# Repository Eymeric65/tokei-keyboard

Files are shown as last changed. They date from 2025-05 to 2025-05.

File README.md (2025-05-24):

# tokei-keyboard
Official repository of the Tokei split keyboard.

This repository is split in the different component in order to make a working Tokei Split keyboard.

*If you are searching the kicad library used in this keyboard you should go to [this repository]*

## Kicad / PCB 

If you directly want to order your board you should directly check [JLCPCB production archive](/kicad/OUTPUT/final-JLCPCB.zip)

Otherwise Kicad project is divided in three :
- The left half
- The right half
- The paneliser to reunion both for production

Electrical output is stored into the **`JLCPCB`** directory, CAD related output is stored in **`CAD`** folder (don't hesitate to check)

## firmware

The `firmware` folder contain ready to flash files in order to test right away the keyboard.

## ZMK

The `zmk-config` file is a direct copy of my `zmk-config` fork for this keyboard. It is the base to the build of the keyboard.

## CAD 

The `CAD` folder contain everything related with the 3D printed cover. I work with Alibre but you can find the ready-to-use `.step` in the `CAD/export` folder.

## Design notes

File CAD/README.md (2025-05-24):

The folder containing everything related with CAD. 

If you are only interested in `.step` there are in export folder.

If you are not familiar with CAD I will strongly advise you to look out for [Alibre](https://www.alibre.com/fr/). From my research there are the only that propose afordable CAD software with forever licence that can be bought by hobbyist. 

Personnaly I came from CATIA (during studying) and even after making a CAR in CATIA (Formula Student), I don't see limitation in Alibre, even if it is a bit slower.

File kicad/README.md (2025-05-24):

Here you can find both of the Kicad project for the right and left halves of the keyboard.
There is also the result of the paneliser in order to merge both halves (cheaper).

I would advise to check the board with your supplier.

If you trust me entirely you can directly use the archive [JLCPC accepted gerber](/OUTPUT/final-JLCPCB.zip) (for reference $32.37 for 5 boards)

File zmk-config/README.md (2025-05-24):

This is a copy of my own version of the zmk-config repo for the Tokei keyboard. 
Not even all the key are binded so, I would advise to check the [keymap](/boards/shields/t_split/t_split.keymap) file.

Base Firmware can be found in the repository [firmware](../firmware/V1.0).

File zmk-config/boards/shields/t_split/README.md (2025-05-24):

#### Note to user:

Fork of the HELIX SHIELD

- If desired, RGB underglow must be manually enabled before building and flashing. Check 'helix.conf' to do so.
- Peripheral RGB function is impaired until full support is implemented in the master branch.
- OLED displays are not currently included in this shield. This will be updated after OLED support is live.
- 'KANA' and 'EISUU' input is currently utilized under the 'LANG1' and 'LANG2' keycodes respectively.

---

Thanks to Nicell, KemoNine, petejohanson, TJ "Chormbo The Great", joelspadin/Rinh, Wofiel, Okke, innovaker,
and the rest of the ZMK contributors for their support in constructing this shield. I appreciate your assistance greatly.
This has been a valuable learning experience for me. May this contribution serve the community well.

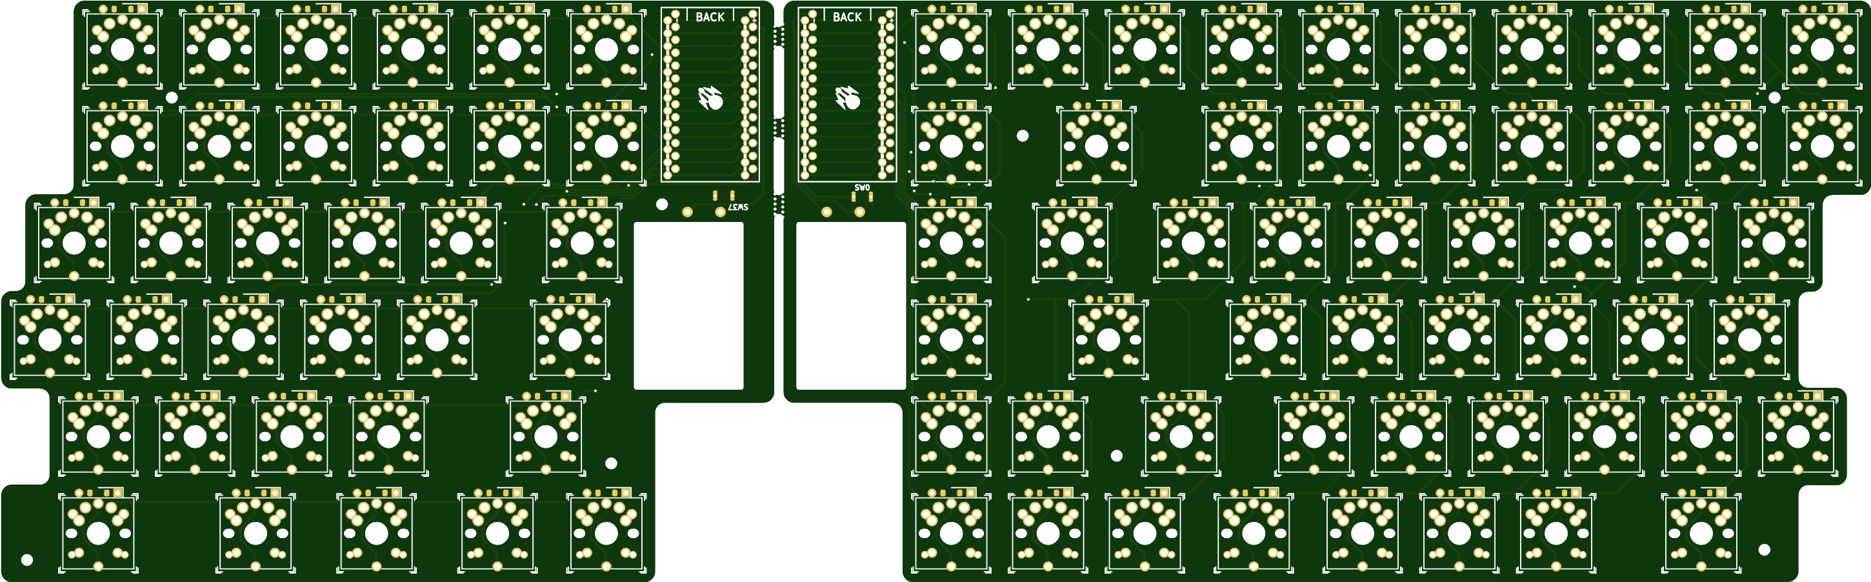
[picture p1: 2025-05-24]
kicad/paneliser/export/Final_Combined_Bottom.png

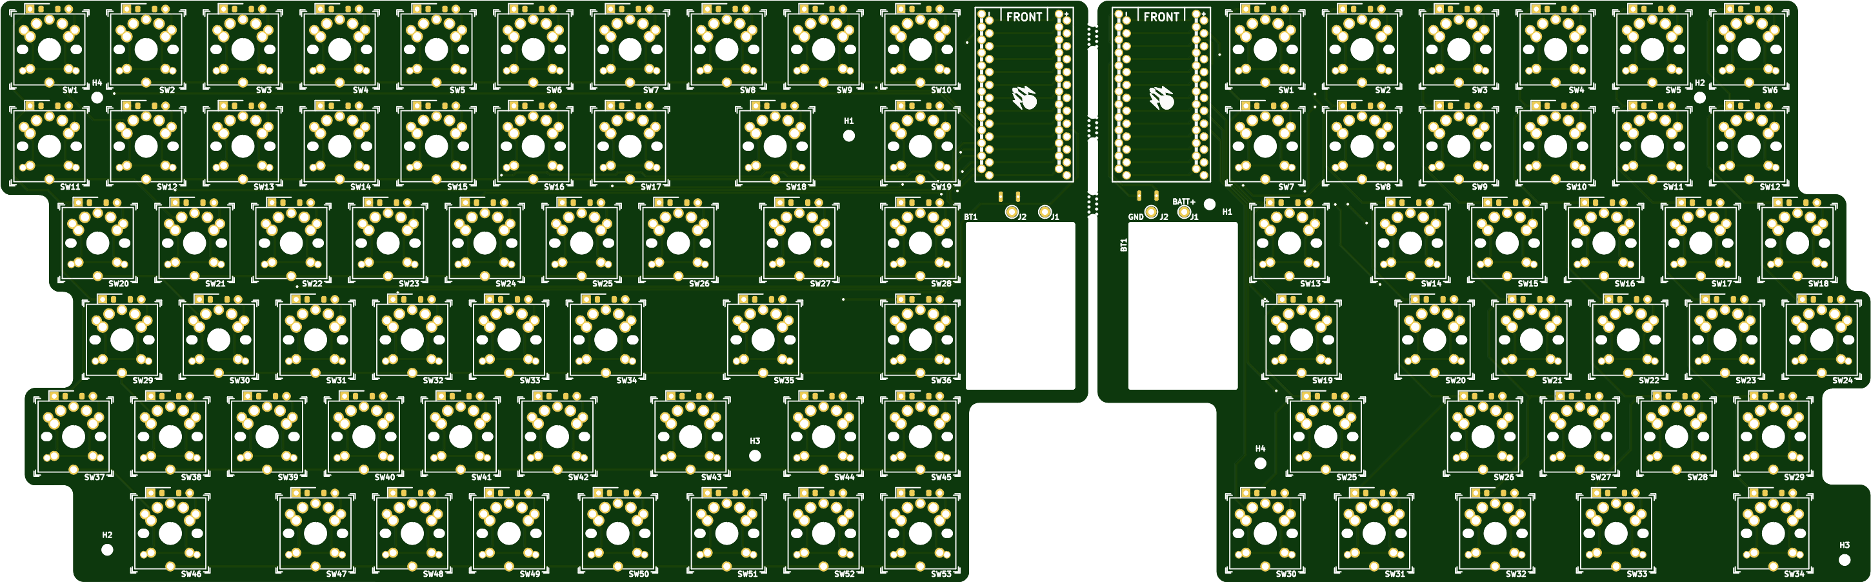
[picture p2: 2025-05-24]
kicad/paneliser/export/Final_Combined_Top.png

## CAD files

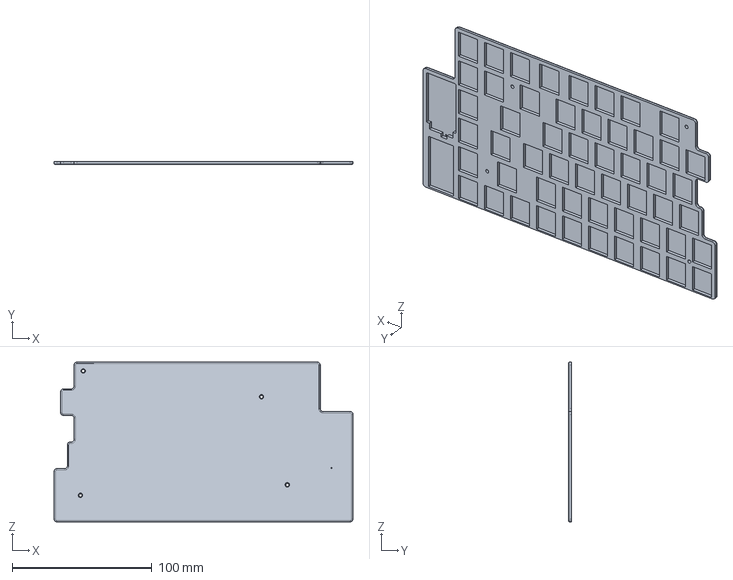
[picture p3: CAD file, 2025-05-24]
CAD/export/Bottom_cover_right_low_profile.stp
213.9 x 2.40 x 114.3 mm

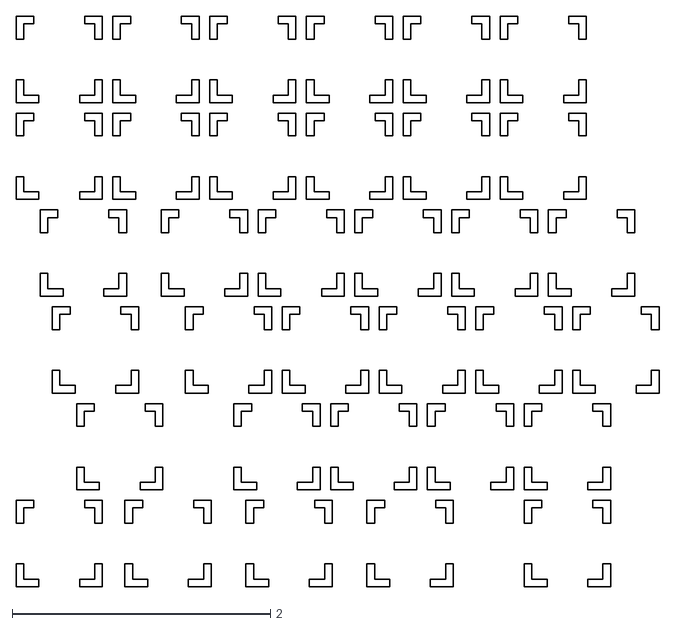
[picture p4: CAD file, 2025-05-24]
kicad/65_split_left/CAD/65_split_left-User_1.dxf
4.98 x 4.42

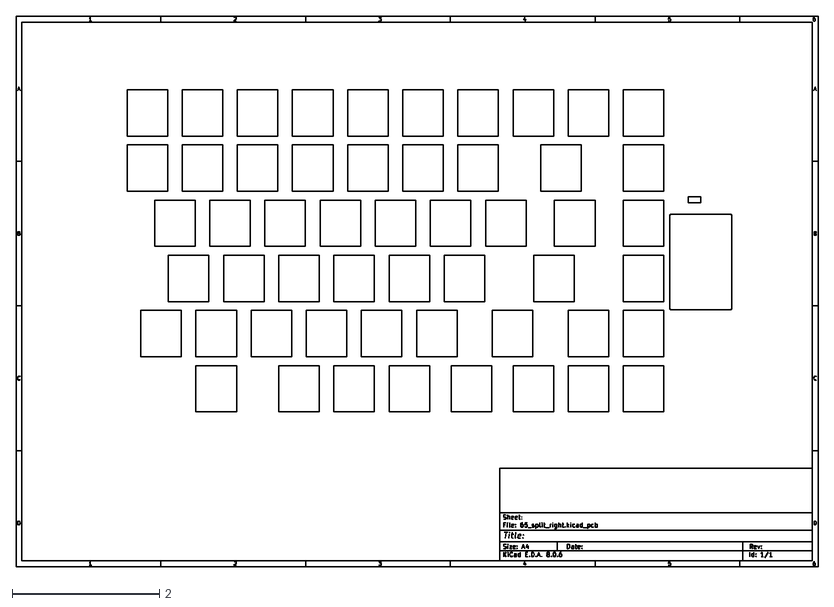
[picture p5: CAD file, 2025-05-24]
kicad/65_split_right/CAD/65_split_right-User_2.dxf
10.9 x 7.48

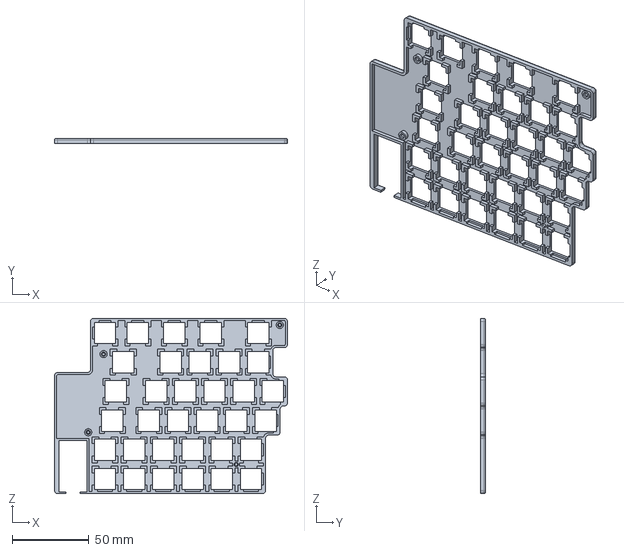
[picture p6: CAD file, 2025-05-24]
CAD/export/Top_cover_left_low_profile.stp
152.0 x 3.55 x 114.3 mm

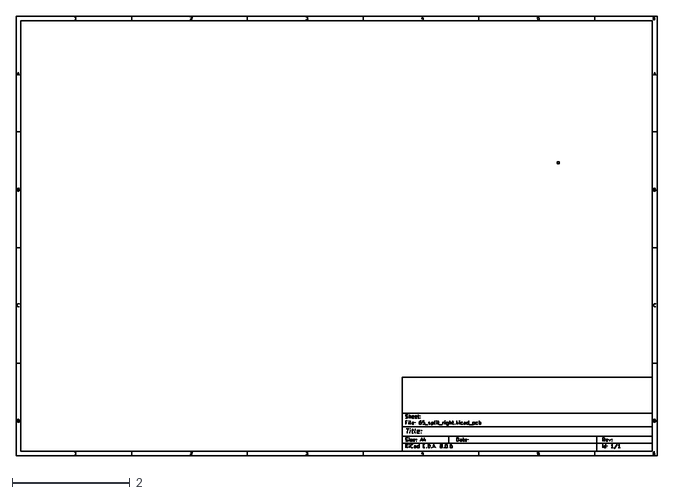
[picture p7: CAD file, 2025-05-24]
kicad/65_split_right/CAD/65_split_right-User_4.dxf
10.9 x 7.48

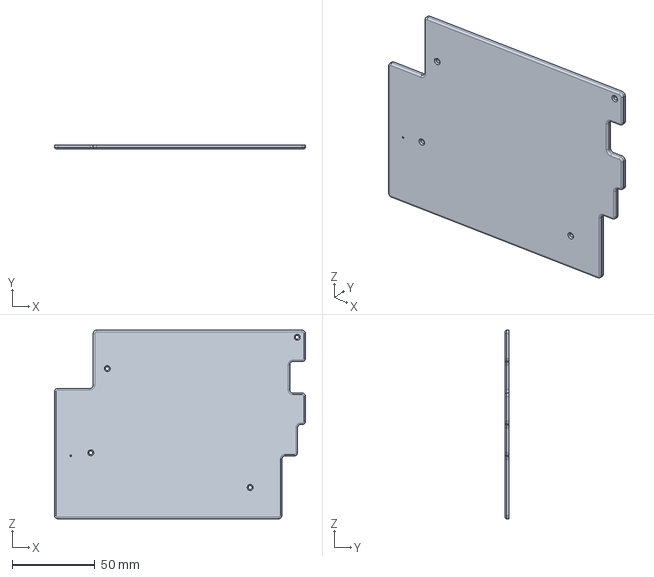
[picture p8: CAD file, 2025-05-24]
CAD/export/Bttom_cover_left_low_profile.stp
152.0 x 2.40 x 114.3 mm

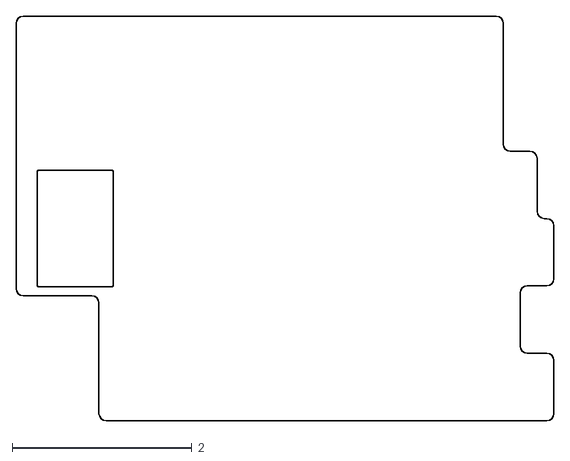
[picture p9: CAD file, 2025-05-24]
kicad/65_split_left/CAD/65_split_left-Edge_Cuts.dxf
5.98 x 4.50

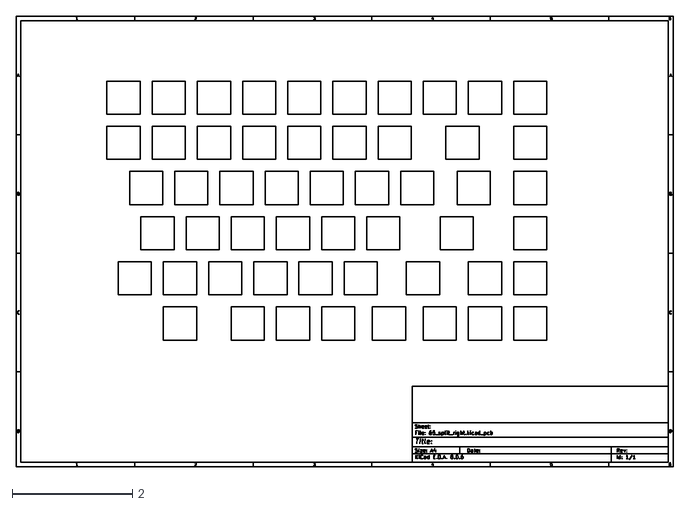
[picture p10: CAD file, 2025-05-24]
kicad/65_split_right/CAD/65_split_right-User_3.dxf
10.9 x 7.48

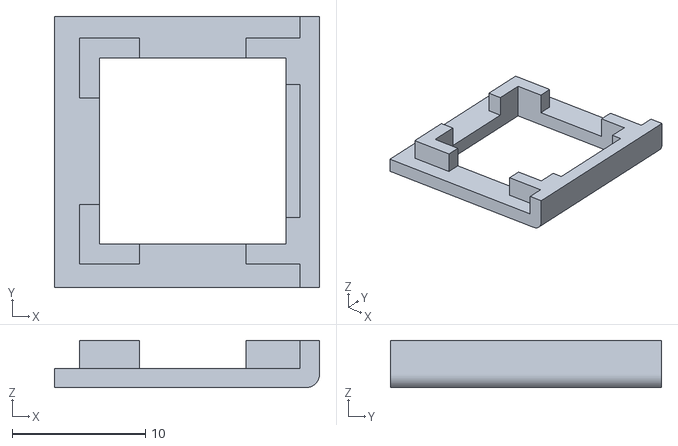
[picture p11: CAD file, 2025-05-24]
CAD/export/one key.stl
19.9 x 20.4 x 3.55

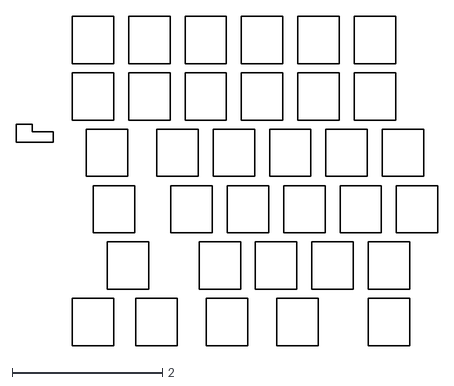
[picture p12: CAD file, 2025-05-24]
kicad/65_split_left/CAD/65_split_left-User_2.dxf
5.61 x 4.38

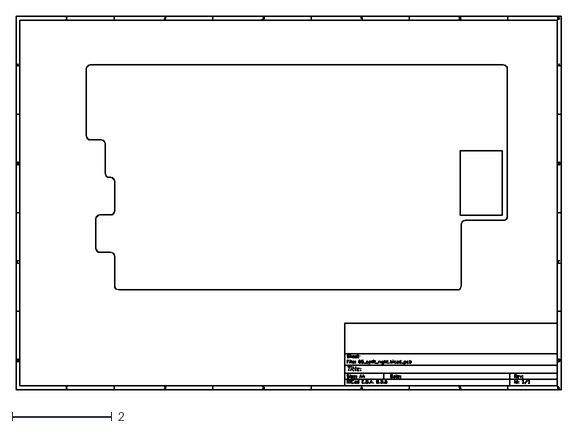
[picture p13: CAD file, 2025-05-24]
kicad/65_split_right/CAD/65_split_right-Edge_Cuts.dxf
10.9 x 7.48

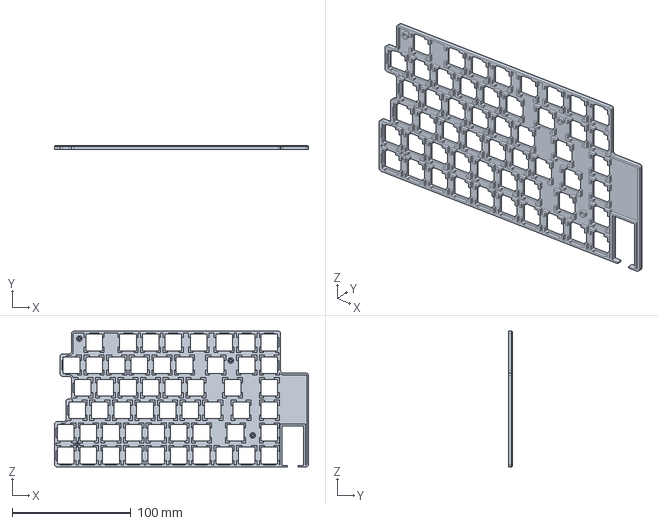
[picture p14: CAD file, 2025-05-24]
CAD/export/Top_cover_right_low_profile.stp
213.9 x 3.55 x 114.3 mm

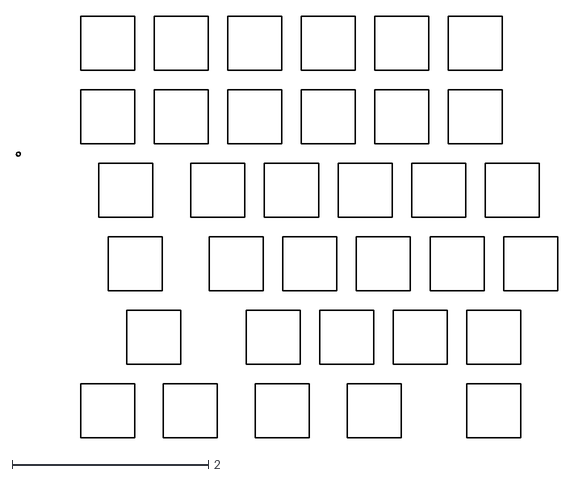
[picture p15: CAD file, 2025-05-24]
kicad/65_split_left/CAD/65_split_left-User_3.dxf
5.52 x 4.30

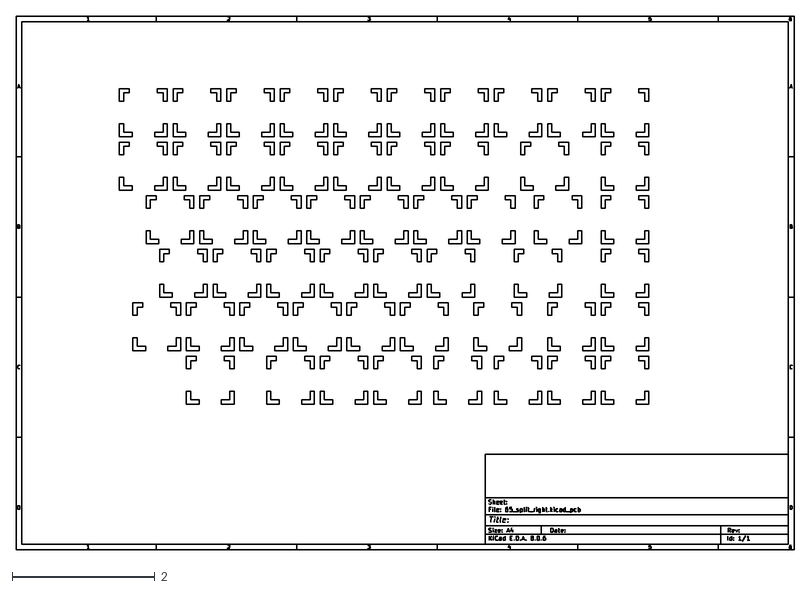
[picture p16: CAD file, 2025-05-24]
kicad/65_split_right/CAD/65_split_right-User_1.dxf
10.9 x 7.48

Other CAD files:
kicad/65_split_left/CAD/65_split_left-User_4.dxf

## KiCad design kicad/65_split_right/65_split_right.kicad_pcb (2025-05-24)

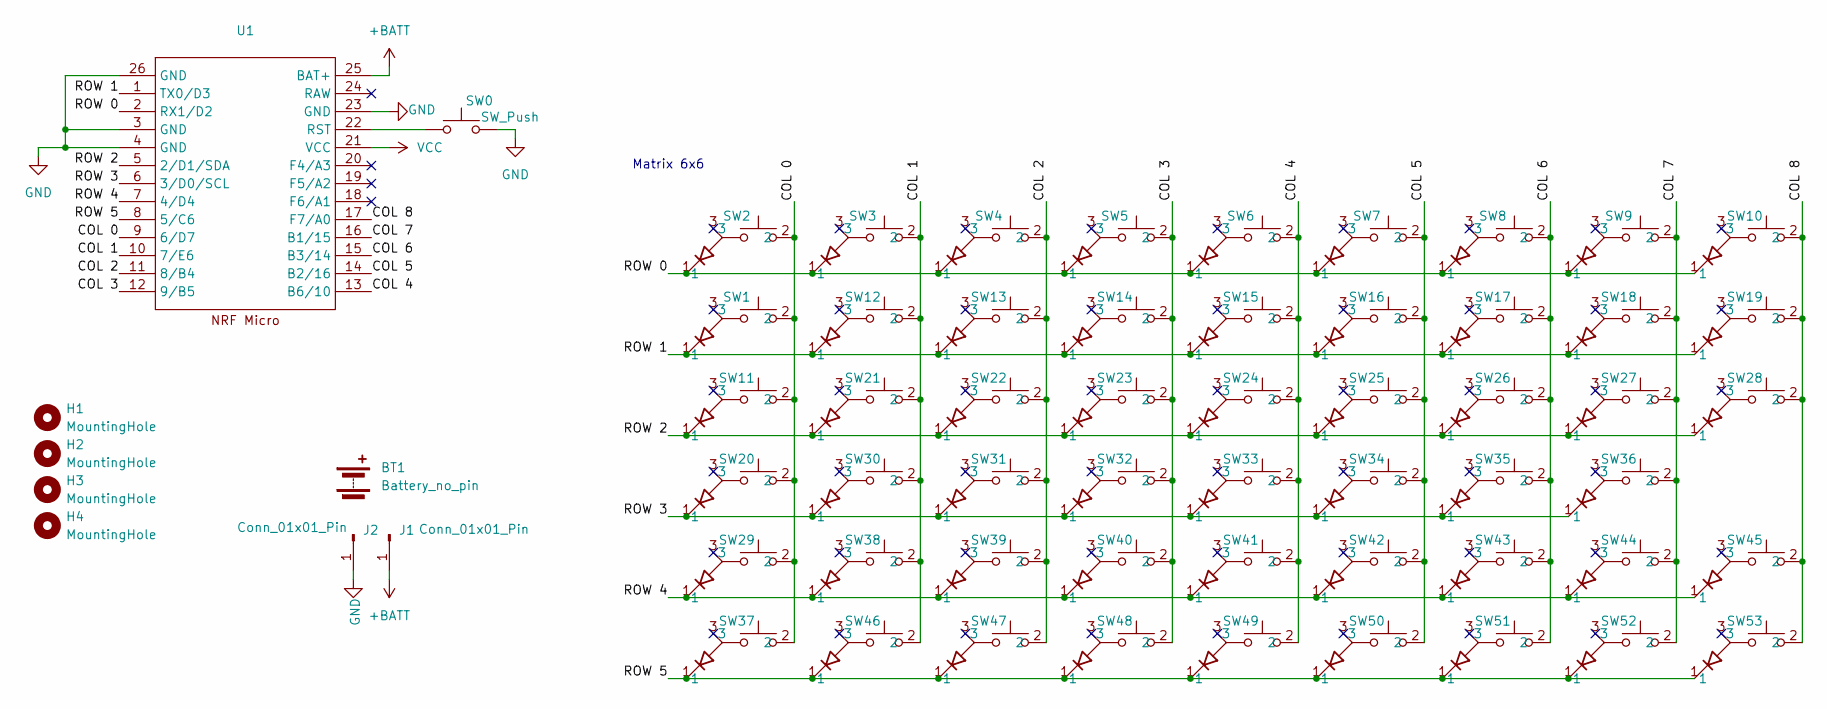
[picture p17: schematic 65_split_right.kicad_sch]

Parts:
BT1: Battery_no_pin; 503020 battery hole
H1, H2, H3, H4: MountingHole; MountingHole_2.2mm_M2_DIN965
J1, J2: Conn_01x01_Pin; Pin_D1.0mm_L10.0mm
SW0: SW_Push; Reset_Switch
SW1, SW2, SW3, SW4, SW5, SW6, SW7, SW8, SW9, SW10, SW11, SW12, SW13, SW14, SW15, SW16, SW17, SW19, SW20, SW21, SW22, SW23, SW24, SW25, SW26, SW28, SW29, SW30, SW31, SW32, SW33, SW34, SW36, SW37, SW38, SW39, SW40, SW41, SW42, SW44, SW45, SW47, SW48, SW49, SW50, SW51, SW52, SW53: SW_UNIVERSAL_1.00u_PCB
SW18, SW46: SW_UNIVERSAL_2.00u_PCB
SW27: SW_UNIVERSAL_1.50u_PCB
SW35: SW_UNIVERSAL_2.25u_PCB
SW43: SW_UNIVERSAL_1.75u_PCB
U1: ProMicro_DUAL

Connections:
+BATT: J1.1, U1.25 (BAT+)
/COL 0: SW1.2, SW2.2, SW11.2, SW20.2, SW29.2, SW37.2, U1.9 (6/D7)
/COL 1: SW3.2, SW12.2, SW21.2, SW30.2, SW38.2, SW46.2, U1.10 (7/E6)
/COL 2: SW4.2, SW13.2, SW22.2, SW31.2, SW39.2, SW47.2, U1.11 (8/B4)
/COL 3: SW5.2, SW14.2, SW23.2, SW32.2, SW40.2, SW48.2, U1.12 (9/B5)
/COL 4: SW6.2, SW15.2, SW24.2, SW33.2, SW41.2, SW49.2, U1.13 (B6/10)
/COL 5: SW7.2, SW16.2, SW25.2, SW34.2, SW42.2, SW50.2, U1.14 (B2/16)
/COL 6: SW8.2, SW17.2, SW26.2, SW35.2, SW43.2, SW51.2, U1.15 (B3/14)
/COL 7: SW9.2, SW18.2, SW27.2, SW36.2, SW44.2, SW52.2, U1.16 (B1/15)
/COL 8: SW10.2, SW19.2, SW28.2, SW45.2, SW53.2, U1.17 (F7/A0)
/ROW 0: SW2.1, SW3.1, SW4.1, SW5.1, SW6.1, SW7.1, SW8.1, SW9.1, SW10.1, U1.2 (RX1/D2)
/ROW 1: SW1.1, SW12.1, SW13.1, SW14.1, SW15.1, SW16.1, SW17.1, SW18.1, SW19.1, U1.1 (TX0/D3)
/ROW 2: SW11.1, SW21.1, SW22.1, SW23.1, SW24.1, SW25.1, SW26.1, SW27.1, SW28.1, U1.5 (2/D1/SDA)
/ROW 3: SW20.1, SW30.1, SW31.1, SW32.1, SW33.1, SW34.1, SW35.1, SW36.1, U1.6 (3/D0/SCL)
/ROW 4: SW29.1, SW38.1, SW39.1, SW40.1, SW41.1, SW42.1, SW43.1, SW44.1, SW45.1, U1.7 (4/D4)
/ROW 5: SW37.1, SW46.1, SW47.1, SW48.1, SW49.1, SW50.1, SW51.1, SW52.1, SW53.1, U1.8 (5/C6)
GND: J2.1, SW0.2, U1.3 (GND), U1.4 (GND), U1.23 (GND), U1.26 (GND)
unnamed: SW0.1, U1.22 (RST)
VCC: U1.21 (VCC)

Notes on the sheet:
Matrix 6x6

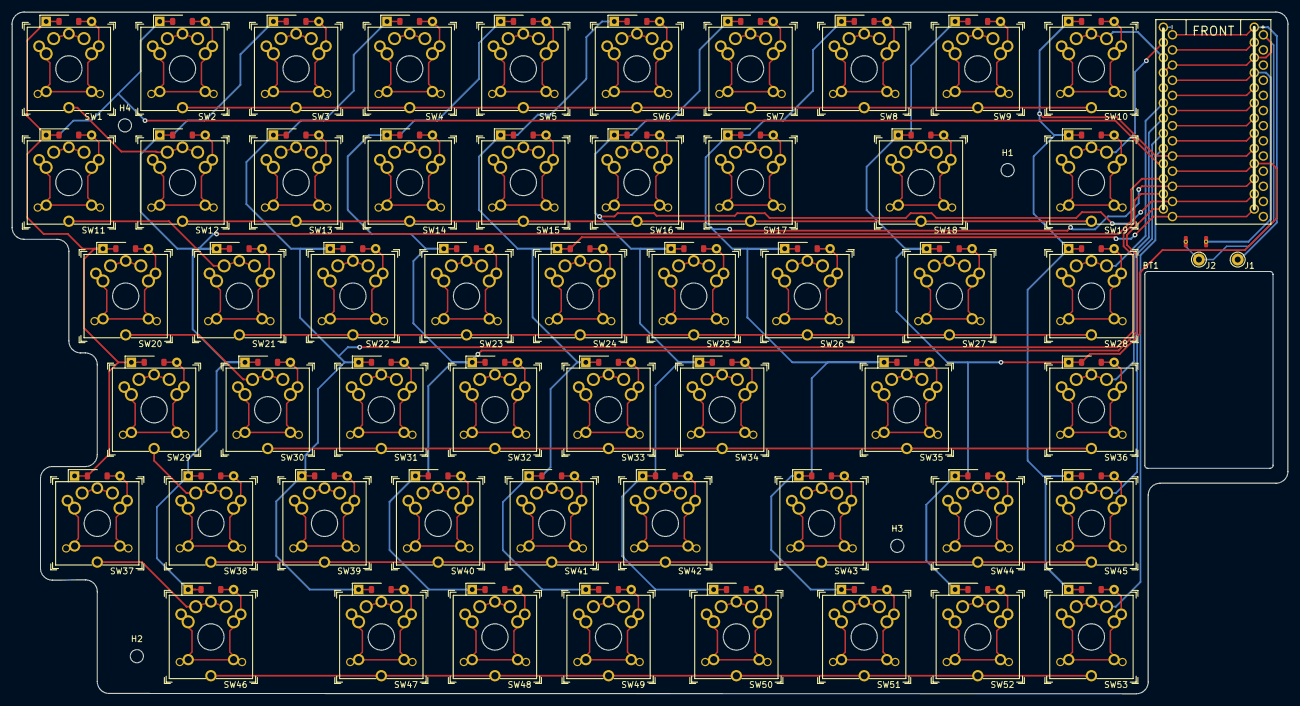
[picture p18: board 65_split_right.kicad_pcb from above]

Board: 2 copper layers, 213.9 x 114.3 mm, 62 parts (1 on the bottom side), 18 nets.

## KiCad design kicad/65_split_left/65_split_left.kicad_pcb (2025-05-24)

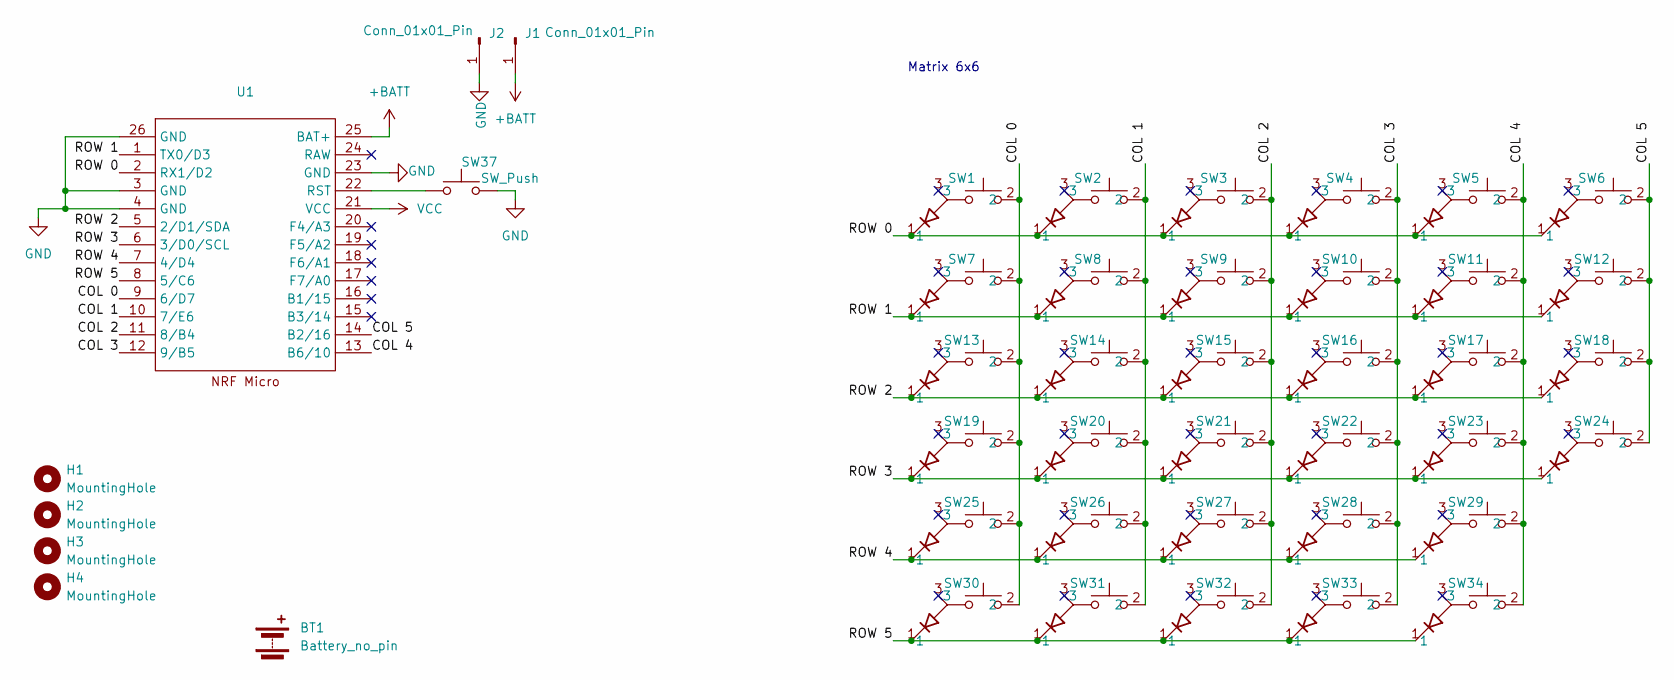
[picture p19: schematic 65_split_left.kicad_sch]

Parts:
BT1: Battery_no_pin; 503020 battery hole
H1, H2, H3, H4: MountingHole; MountingHole_2.2mm_M2_DIN965
J1, J2: Conn_01x01_Pin; Pin_D1.0mm_L10.0mm
SW1, SW2, SW3, SW4, SW5, SW6, SW7, SW8, SW9, SW10, SW11, SW12, SW14, SW15, SW16, SW17, SW18, SW20, SW21, SW22, SW23, SW24, SW26, SW27, SW28, SW29, SW30: SW_UNIVERSAL_1.00u_PCB
SW13: SW_UNIVERSAL_1.50u_PCB
SW19: SW_UNIVERSAL_1.75u_PCB
SW25: SW_UNIVERSAL_2.25u_PCB
SW31, SW32, SW33: SW_UNIVERSAL_1.25u_PCB
SW34: SW_UNIVERSAL_2.00u_PCB
SW37: SW_Push; Reset_Switch
U1: ProMicro_DUAL

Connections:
+BATT: J1.1, U1.25 (BAT+)
/COL 0: SW1.2, SW7.2, SW13.2, SW19.2, SW25.2, SW30.2, U1.9 (6/D7)
/COL 1: SW2.2, SW8.2, SW14.2, SW20.2, SW26.2, SW31.2, U1.10 (7/E6)
/COL 2: SW3.2, SW9.2, SW15.2, SW21.2, SW27.2, SW32.2, U1.11 (8/B4)
/COL 3: SW4.2, SW10.2, SW16.2, SW22.2, SW28.2, SW33.2, U1.12 (9/B5)
/COL 4: SW5.2, SW11.2, SW17.2, SW23.2, SW29.2, SW34.2, U1.13 (B6/10)
/COL 5: SW6.2, SW12.2, SW18.2, SW24.2, U1.14 (B2/16)
/ROW 0: SW1.1, SW2.1, SW3.1, SW4.1, SW5.1, SW6.1, U1.2 (RX1/D2)
/ROW 1: SW7.1, SW8.1, SW9.1, SW10.1, SW11.1, SW12.1, U1.1 (TX0/D3)
/ROW 2: SW13.1, SW14.1, SW15.1, SW16.1, SW17.1, SW18.1, U1.5 (2/D1/SDA)
/ROW 3: SW19.1, SW20.1, SW21.1, SW22.1, SW23.1, SW24.1, U1.6 (3/D0/SCL)
/ROW 4: SW25.1, SW26.1, SW27.1, SW28.1, SW29.1, U1.7 (4/D4)
/ROW 5: SW30.1, SW31.1, SW32.1, SW33.1, SW34.1, U1.8 (5/C6)
GND: J2.1, SW37.2, U1.3 (GND), U1.4 (GND), U1.23 (GND), U1.26 (GND)
unnamed: SW37.1, U1.22 (RST)
VCC: U1.21 (VCC)

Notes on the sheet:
Matrix 6x6

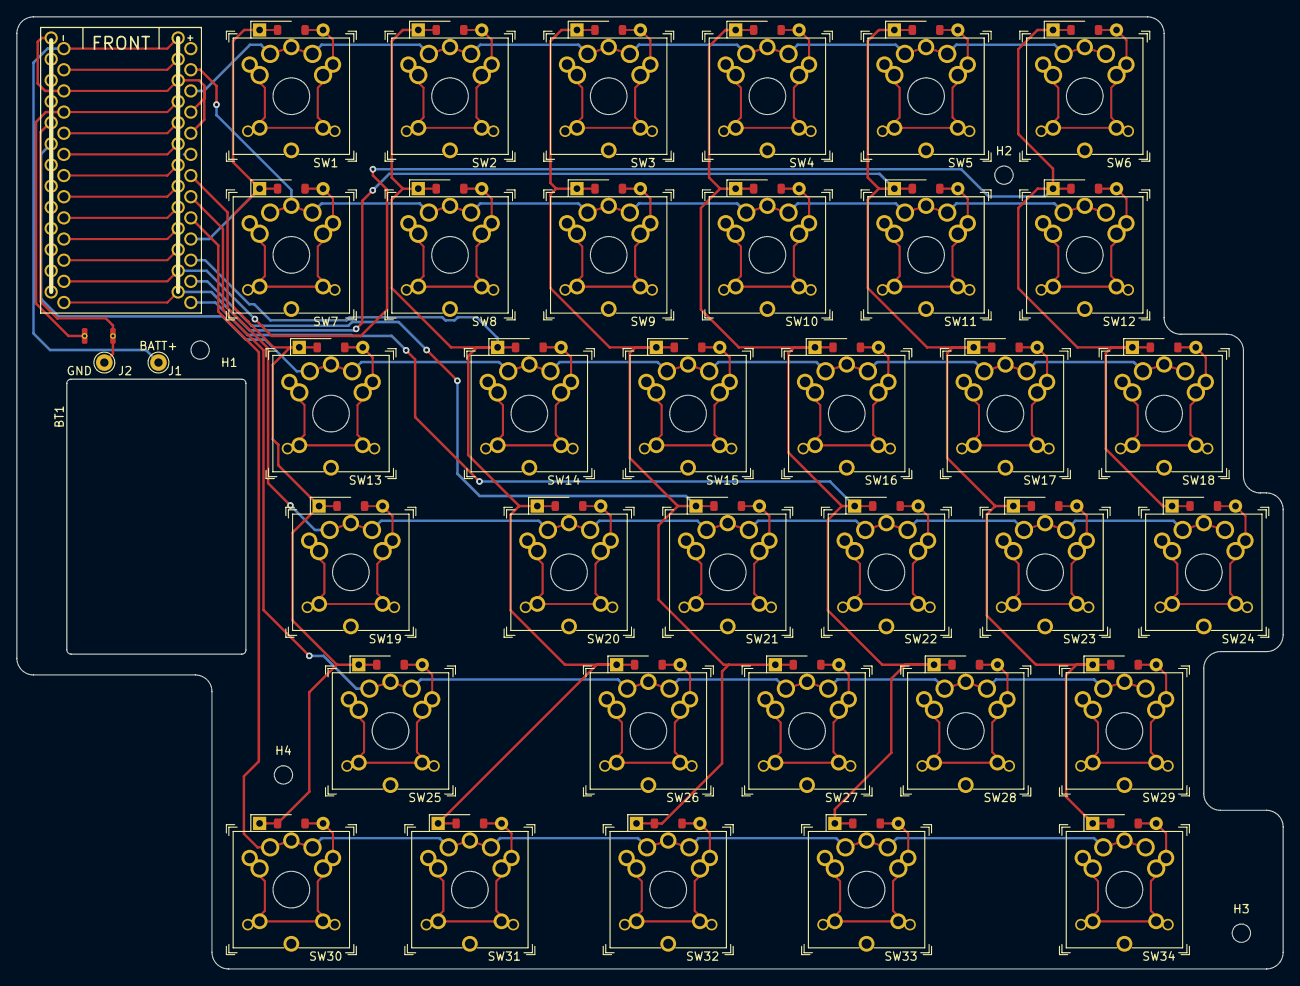
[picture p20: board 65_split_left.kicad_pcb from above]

Board: 2 copper layers, 152.0 x 114.3 mm, 43 parts (1 on the bottom side), 15 nets.
